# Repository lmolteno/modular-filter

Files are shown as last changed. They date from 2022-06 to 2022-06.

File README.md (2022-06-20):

Modular filters currently include:
 - All pass filter (phase shift as function of frequency, minimal amplitude response)
 - Low pass filter (10k-30k cutoff, i.e. distance filter, as higher frequencies get attenuated at distance)
 - Non-linear amplifier
 - Magnetic saturation with inductor (could fiddle with iron core as parameter)

The idea is to have a swappable bay of some description, with the right level of abstraction as it were that filter design becomes easy. For this reason, the connector has signal in, signal out, +5V, -5V and ground.
Ideally, aesthetics will also not be horrible.

# V1
V1's construction was alright, though there were mistakes made on the values of capacitor bought, so performance was mediocre.
The input stage had some issues, solved by swapping the T and R on the input to the opamp (i.e. inverting the inputs).
The bypass also causes strange issues where it over the course of a few seconds causes greater and greater amounts of clipping on the input signal.

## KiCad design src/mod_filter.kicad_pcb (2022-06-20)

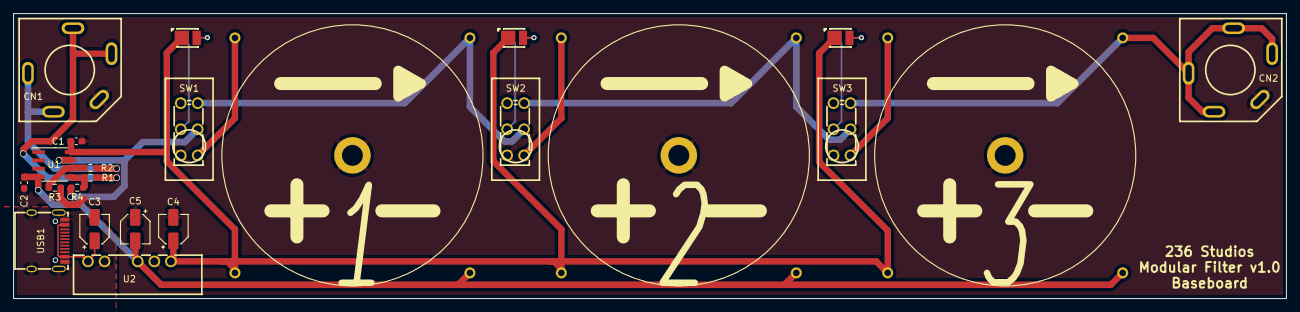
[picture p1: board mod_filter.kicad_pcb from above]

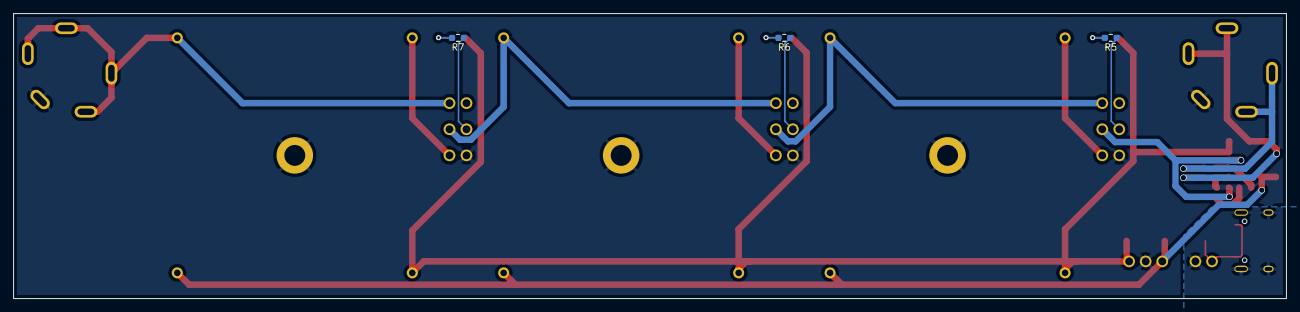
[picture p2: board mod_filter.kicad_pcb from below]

Board: 2 copper layers, 195.0 x 43.7 mm, 26 parts (3 on the bottom side), 22 nets.

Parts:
C1, C2: 0.1u; C_0603_1608Metric_Pad1.08x0.95mm_HandSolder
C3, C4, C5: 4.7u; CP_Elec_4x5.4
CN1: INPUT; AUDIO-TH_CK6.35-3-14-18LF
CN2: OUTPUT; AUDIO-TH_CK6.35-3-14-18LF
F1, F2, F3: Molteno_Filter
LED1, LED2, LED3: RED; LED-SMD_L3.5-W2.8-R-FD_TJ-S2835UG5W8TLC2R-A5
R1, R2, R3, R4: 1K; R_0603_1608Metric_Pad0.98x0.95mm_HandSolder
R5, R6, R7: 220; R_0603_1608Metric_Pad0.98x0.95mm_HandSolder
SW1, SW2, SW3: BYPASS; SW-TH_SS-22F24AT10
U1: TL062; SOIC-8_3.9x4.9mm_P1.27mm
U2: A0505S-1WR3; PWRM-TH_A05XXS-1WR3
USB1: TYPEC-304-BCP16; USB-C-SMD_TYPEC-304-BCP16

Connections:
5V_GND: C3.2, U2.2 (GND), USB1.13 (GND), USB1.14 (GND), USB1.15 (GND), USB1.16 (GND), USB1.A1B12 (GND), USB1.B1A12 (GND)
5V_IN: C3.1, U2.1 (VIN), USB1.A4B9 (VBUS), USB1.B4A9 (VBUS)
+5V: C1.1, C4.1, F1.3 (V+), F2.3 (V+), F3.3 (V+), LED1.2 (+), LED2.2 (+), LED3.2 (+), U1.8 (V+), U2.6 (+VO)
-5V: C2.1, C5.2, F1.4 (V-), F2.4 (V-), F3.4 (V-), U1.4 (V-), U2.4 (-VO)
/1->2: F1.2 (OUT), SW1.6, SW2.5
/2->3: F2.2 (OUT), SW2.6, SW3.5
/IN_R: CN1.2, CN1.4, R2.1
/IN_T: CN1.3, CN1.5, R1.1
GND: C1.2, C2.2, C4.2, C5.1, CN1.1, CN2.1, F1.5 (GND), F2.5 (GND), F3.5 (GND), R3.1, SW1.1, SW2.1, SW3.1, U2.5 (0V)
IN: R4.2, SW1.5, U1.7
unnamed: F1.1 (IN), SW1.4
unnamed: F2.1 (IN), SW2.4
unnamed: F3.1 (IN), SW3.4
unnamed: LED1.1 (-), R5.2
unnamed: LED2.1 (-), R6.2
unnamed: LED3.1 (-), R7.2
unnamed: R1.2, R4.1, U1.5 (+)
unnamed: R2.2, R3.2, U1.6 (-)
unnamed: R5.1, SW1.2
unnamed: R6.1, SW2.2
unnamed: R7.1, SW3.2
TS_OUT: CN2.2, CN2.3, CN2.4, CN2.5, F3.2 (OUT), SW3.6

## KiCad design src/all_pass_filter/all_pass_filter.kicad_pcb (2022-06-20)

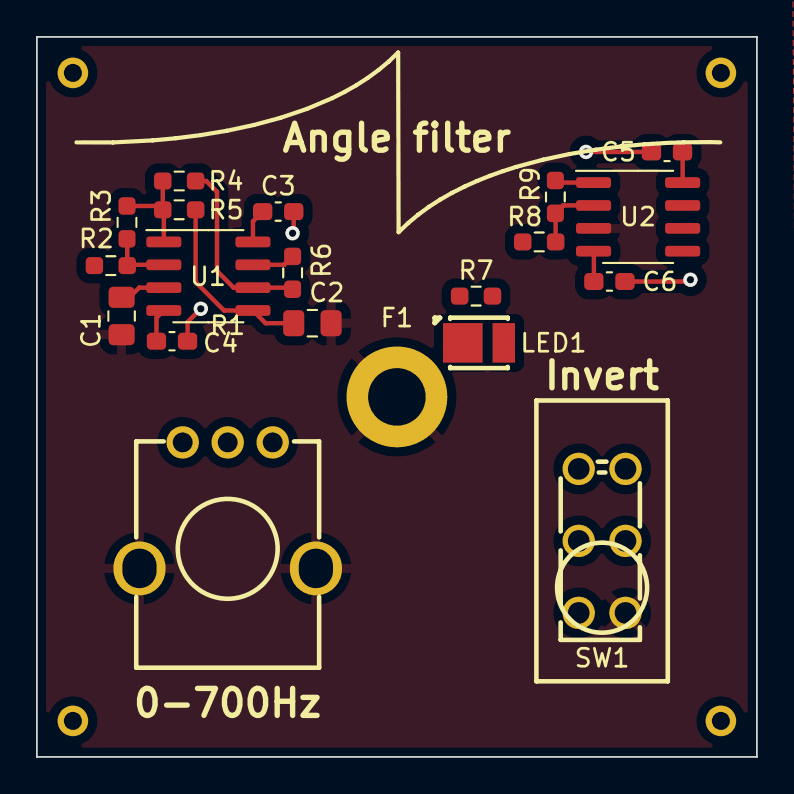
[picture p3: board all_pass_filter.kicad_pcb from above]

Board: 4 copper layers, 40.0 x 40.0 mm, 20 parts (0 on the bottom side), 19 nets.

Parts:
C1, C2: 4.7u; C_0805_2012Metric_Pad1.18x1.45mm_HandSolder
C3, C4, C5, C6: 0.1u; C_0603_1608Metric_Pad1.08x0.95mm_HandSolder
F1: Molteno_Filter; Molteno_Filter_Clean
LED1: INVERT_INDICATOR; LED-SMD_L3.5-W2.8-R-FD_TJ-S2835UG5W8TLC2R-A5
R1: 5k; RES-ADJ-TH_RK09K1130AJ3
R2, R3, R4, R6, R8, R9: 100; R_0603_1608Metric_Pad0.98x0.95mm_HandSolder
R5: 2.2k; R_0603_1608Metric_Pad0.98x0.95mm_HandSolder
R7: 220; R_0603_1608Metric_Pad0.98x0.95mm_HandSolder
SW1: INVERT; SW-TH_SS-22F24AT10
U1, U2: LM833; SOIC-8_3.9x4.9mm_P1.27mm

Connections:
+5V: C3.2, C5.2, F1.3 (V+)
-5V: C4.2, C6.2, F1.4 (V-)
AP_OUT: R6.2, SW1.2, U1.7
GND: C1.2, C2.2, F1.5 (GND), R1.4, R1.5, SW1.4, U2.3 (+)
IN: F1.1 (IN), R1.2, R2.1
INV_IN: R8.1, SW1.1
unnamed: C1.1, R1.3, U1.3 (+)
unnamed: C2.1, R5.2, U1.5 (+)
unnamed: LED1.1 (-), R7.2
unnamed: R2.2, R3.1, U1.2 (-)
unnamed: R3.2, R4.1, R5.1, U1.1
unnamed: R4.2, R6.1, U1.6 (-)
unnamed: R7.1, SW1.5
unnamed: R8.2, R9.1, U2.2 (-)
unnamed: C4.1, U1.4 (V-)
unnamed: C3.1, U1.8 (V+)
unnamed: C6.1, U2.4 (V-)
unnamed: C5.1, U2.8 (V+)
OUT: F1.2 (OUT), R9.2, SW1.3, U2.1
